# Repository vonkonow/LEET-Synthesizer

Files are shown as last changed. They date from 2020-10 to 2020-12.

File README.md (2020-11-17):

# LEET-Synthesizer
This is the GitHub repository containing the 3D models and source code for the LEET Synthesizer devices: https://vonkonow.com/wordpress/leet-synthesizer/

Description: LEET is a modular & affordable ($6) MIDI synth for your favorite DAW.

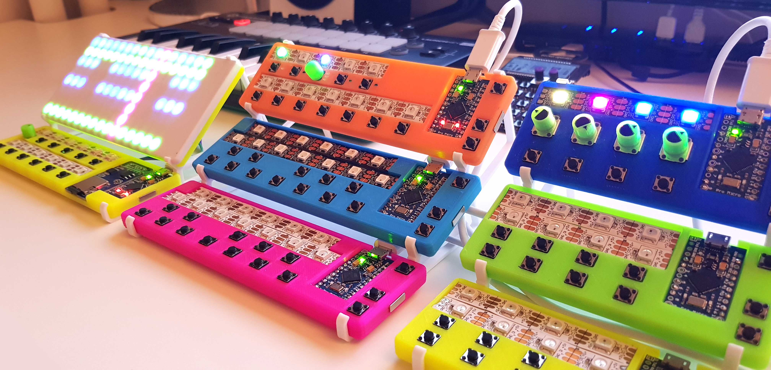
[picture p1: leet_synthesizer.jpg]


I have designed a keyboard, drum pad, chord keyboard, arpeggiator and a step sequencer all with RGB LEDs for playback visualization.
They are easy to build and anyone with a 3D printer and basic soldering skills should be able to replicate them. Everything is open source and hacking is encouraged!

Check out the forum where you can get support and subscribe to get noticed when new devices are released: https://vonkonow.com/wordpress/forums/topic/project-updates/

For detailed building instructions visit: https://vonkonow.com/wordpress/leet-synthesizer/

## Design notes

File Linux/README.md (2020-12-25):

This is the GitHub repository containing the 3D models and files for the LEET Linux device: https://vonkonow.com/wordpress/leet-linux/
Description:
Linux based sound synthesis for LEET modules (or any other MIDI keyboard). Different sound engines can be loaded for high quality sound instruments.

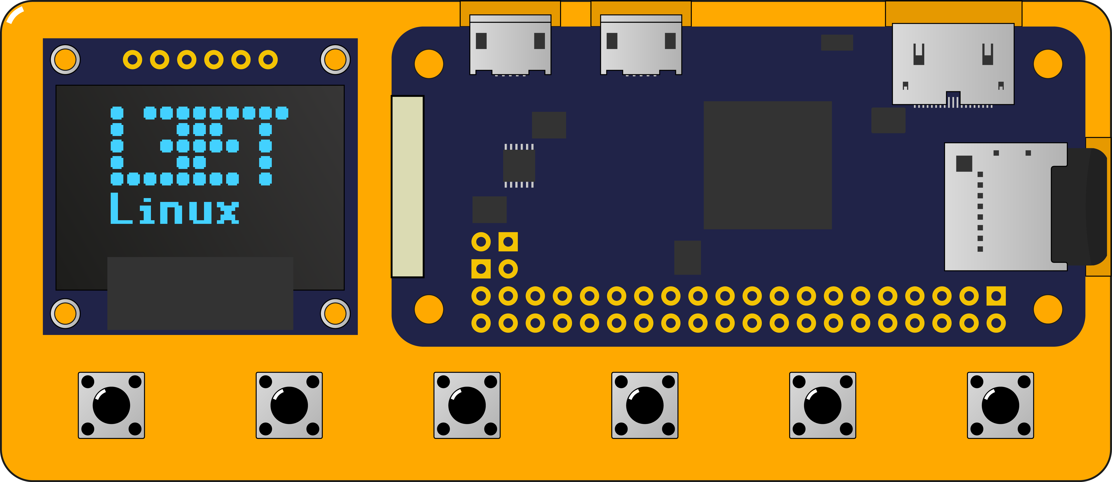
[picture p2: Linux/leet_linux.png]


The parent project (LEET Synthesizer) also contains; a keyboard, drum pad, chord keyboard, control, arpeggiator and a step sequencer, all with RGB LEDs for playback visualization. They are easy to build and anyone with a 3D printer and basic soldering skills should be able to replicate them. Everything is open source and hacking is encouraged!
For detailed building instructions visit: https://vonkonow.com/wordpress/leet-linux/

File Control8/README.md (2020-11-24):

This is the GitHub repository containing the 3D models and source code for the LEET Control8: https://vonkonow.com/wordpress/leet-control8/

Description:

The LEET Control8 is a miniature MIDI accessory suitable for controlling up to eight analog settings in your DAW, like; volume, oscillators, envelope or filters. It is low cost, easy to build and compact in size. 

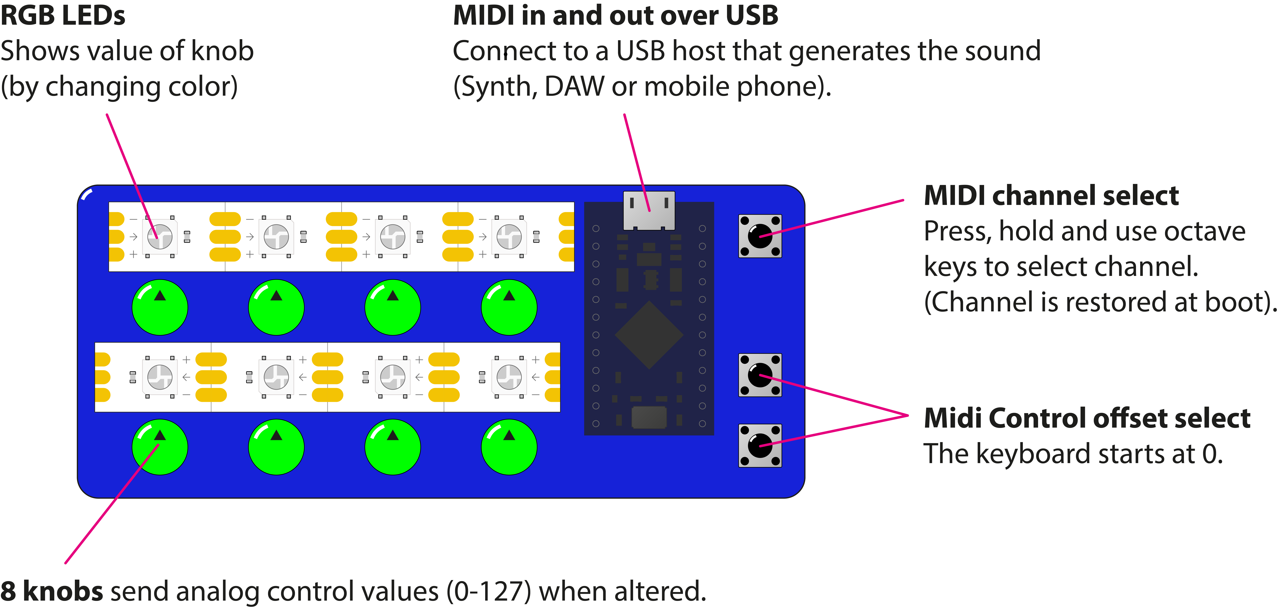
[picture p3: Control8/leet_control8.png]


The parent project (LEET Synthesizer) also contains; a keyboard, drum pad, chord keyboard, arpeggiator and a step sequencer, all with RGB LEDs for playback visualization. They are easy to build and anyone with a 3D printer and basic soldering skills should be able to replicate them. Everything is open source and hacking is encouraged!

For detailed building instructions visit: https://vonkonow.com/wordpress/leet-control8/

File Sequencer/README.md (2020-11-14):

This is the GitHub repository containing the 3D models and source code for the LEET sequencer: https://vonkonow.com/wordpress/leet-sequencer/

## Description:
The LEET Sequencer is a miniature 16-step MIDI sequencer with 8 channels. It is low cost, easy to build and compact in size. It has full color LED blinkenlights for playback and record visualization.

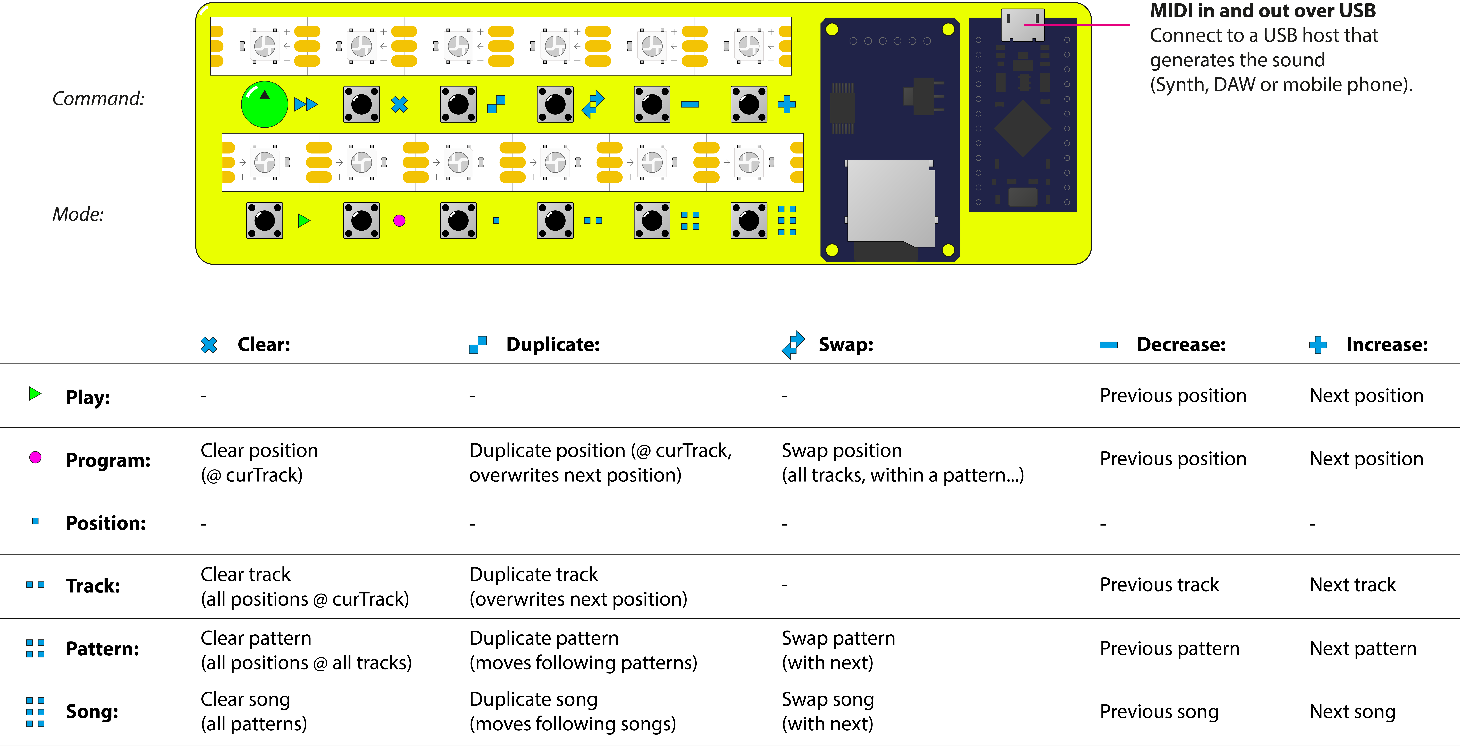
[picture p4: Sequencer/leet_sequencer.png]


The parent project (LEET Synthesizer) also contains; a keyboard, drum pad, chord keyboard, control unit and arpeggiator, all with RGB LEDs for playback visualization. They are easy to build and anyone with a 3D printer and basic soldering skills should be able to replicate them. Everything is open source and hacking is encouraged!

For building instructions visit: https://vonkonow.com/wordpress/leet-sequencer/

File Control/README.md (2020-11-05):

This is the GitHub repository containing the 3D models and source code for the LEET Control: https://vonkonow.com/wordpress/leet-control/

Description: 

The LEET Control is a miniature MIDI accessory suitable for controlling settings in your DAW, like volume, decay or filters. 
It is low cost, easy to build and compact in size. With a different firmware it can also work as an arpeggiator.

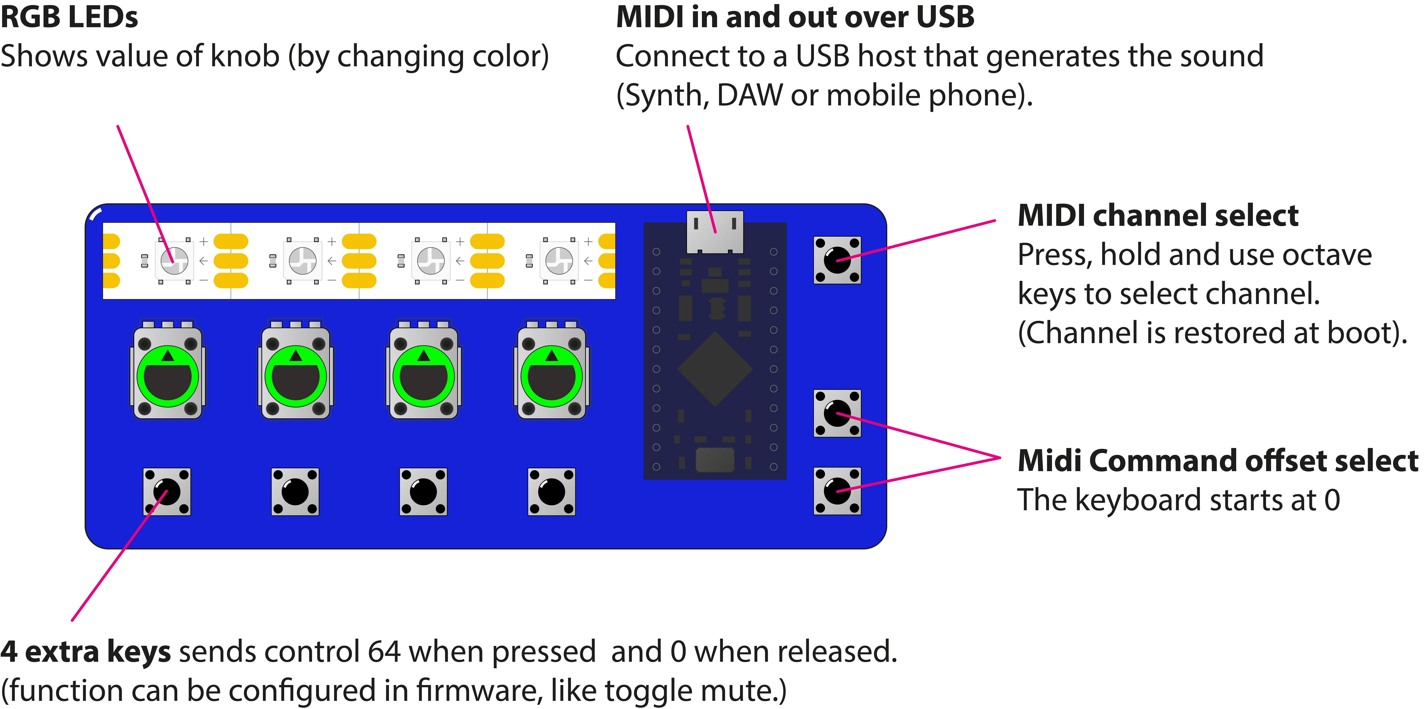
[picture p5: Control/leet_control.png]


The [parent project (LEET Synthesizer)](https://vonkonow.com/wordpress/leet-synthesizer/) also contains; a drum pad, chord keyboard, arpeggiator and a step sequencer, all with RGB LEDs for playback visualization.
They are easy to build and anyone with a 3D printer and basic soldering skills should be able to replicate them. Everything is open source and hacking is encouraged!

For detailed building instructions visit: https://vonkonow.com/wordpress/leet-control/

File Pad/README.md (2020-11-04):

This is the GitHub repository containing the 3D models and source code for the LEET pad: https://vonkonow.com/wordpress/leet-pad/

Description: 

The LEET Pad is a miniature MIDI keyboard suitable for drums and effects. 
It is low cost, easy to build and compact in size. It has full color LED blinkenlights for playback visualization.

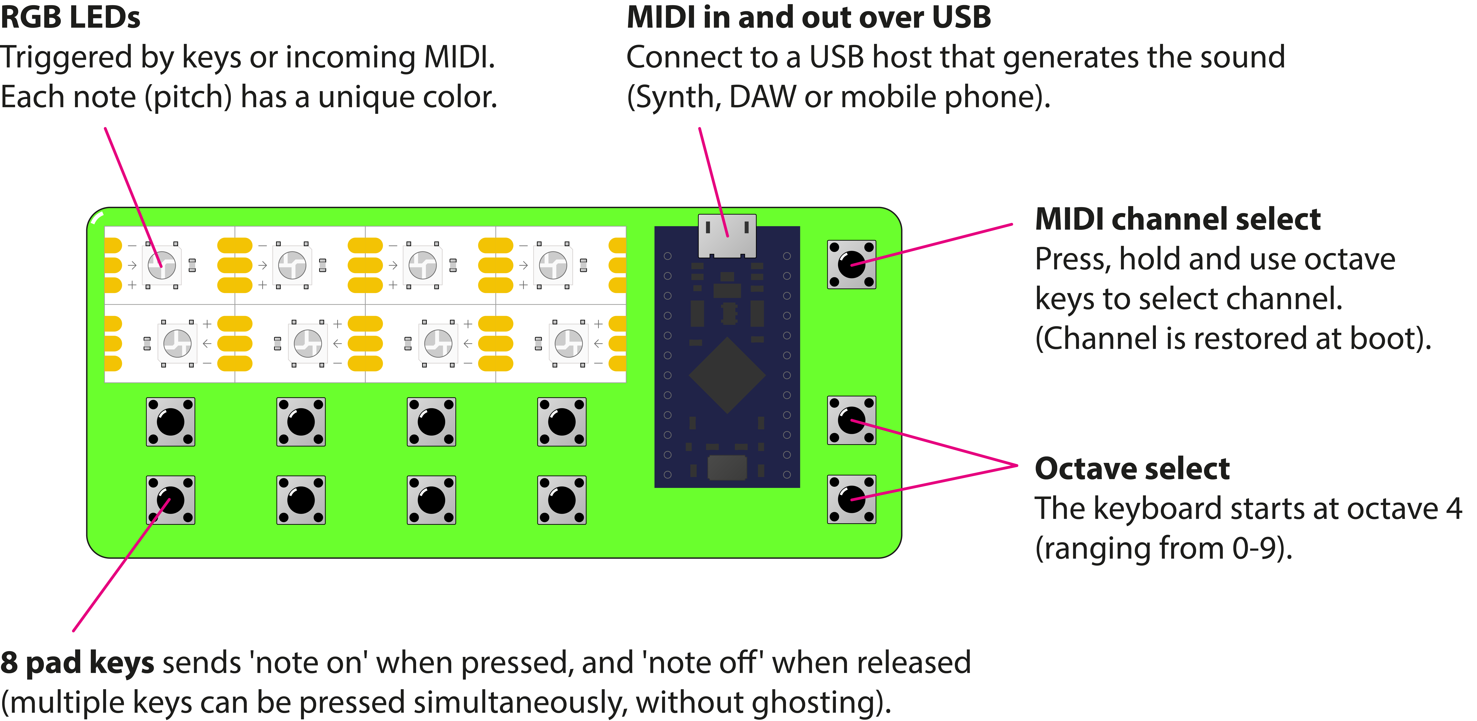
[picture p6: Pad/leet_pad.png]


The [parent project (LEET Synthesizer)](https://vonkonow.com/wordpress/leet-synthesizer/) also contains; a drum pad, chord keyboard, arpeggiator and a step sequencer, all with RGB LEDs for playback visualization.
They are easy to build and anyone with a 3D printer and basic soldering skills should be able to replicate them. Everything is open source and hacking is encouraged!

For detailed building instructions visit: https://vonkonow.com/wordpress/leet-pad/

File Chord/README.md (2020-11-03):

This is the GitHub repository containing the 3D models and source code for the LEET Chord keyboard: https://vonkonow.com/wordpress/leet-chord/

Description: 

The LEET Chord keyboard is a MIDI keyboard that plays chords of your choice. It is easy to build, affordable and has beautiful RGB LED blinkenlights. Adjust number of notes, scale, tonic and root. It is perfect for chord progressions (I – V – vi – IV ;)

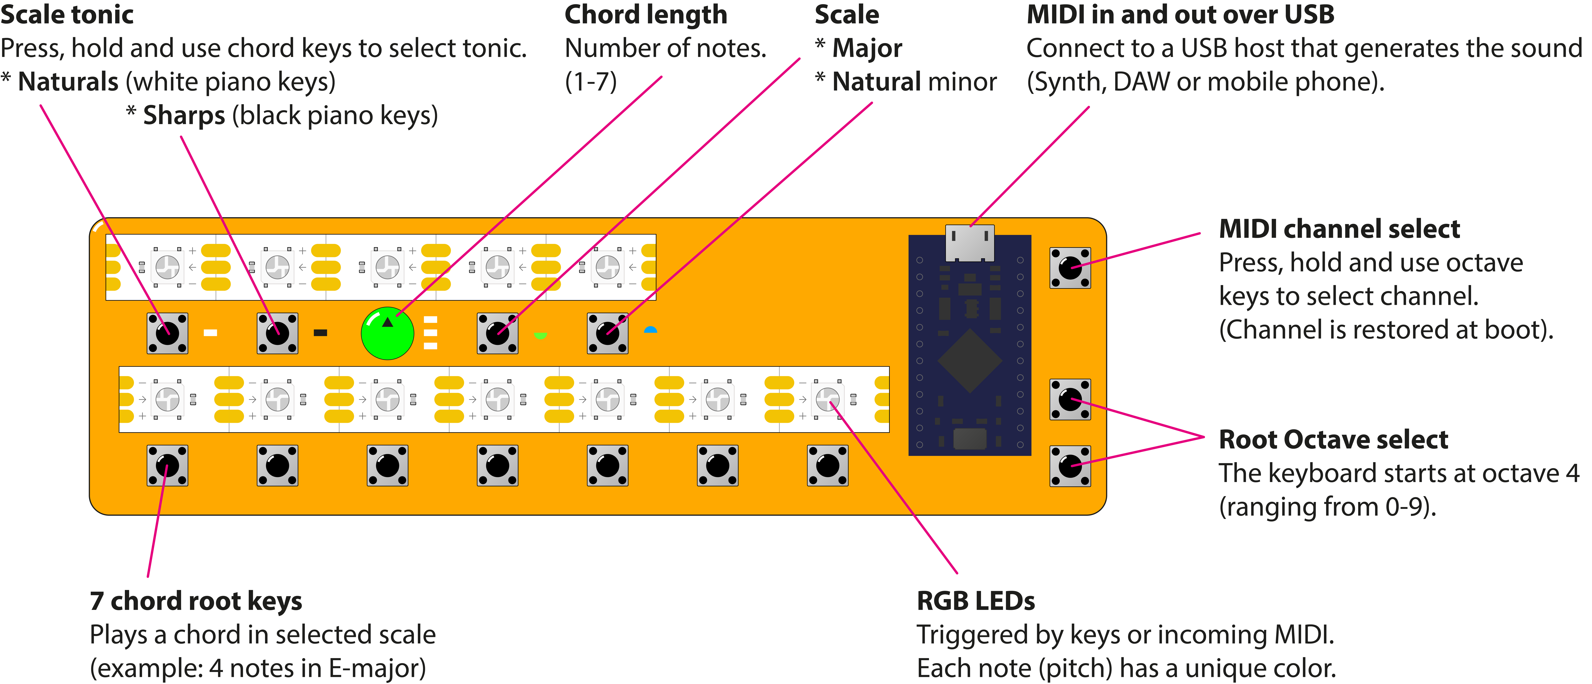
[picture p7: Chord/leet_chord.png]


The [parent project (LEET Synthesizer)](https://vonkonow.com/wordpress/leet-synthesizer/) also contains; a drum pad, chord keyboard, arpeggiator and a step sequencer, all with RGB LEDs for playback visualization.
They are easy to build and anyone with a 3D printer and basic soldering skills should be able to replicate them. Everything is open source and hacking is encouraged!

For detailed building instructions visit: https://vonkonow.com/wordpress/leet-chord/

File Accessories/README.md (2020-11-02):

# This folder contains the 3D models for LEET accessories, like stands, knobs, nametag and clip. 
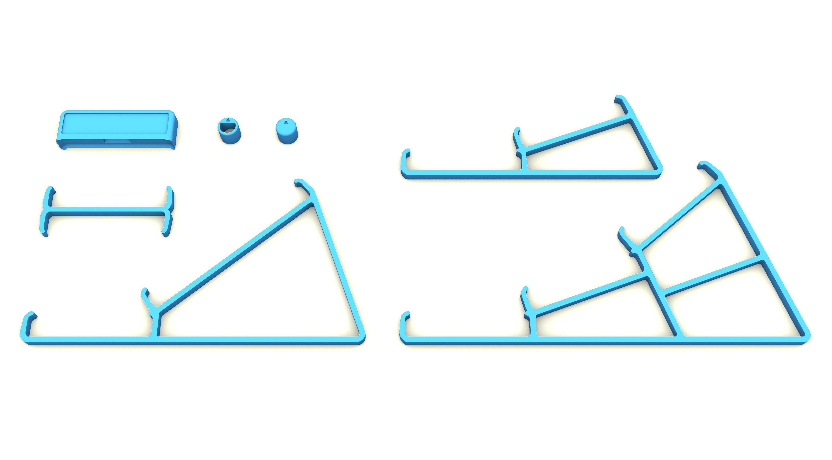
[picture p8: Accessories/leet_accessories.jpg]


## Stands and clip:
The stands and clip are used to group LEET devices in 3D. They are 0.2mm smaller than the units in order to tightly secure them. It is rather important that your 3D printer has a correct flow (too much and the fit will be too tight, too low and the fit will be too loose).
The clip_dual is used to hold two units in place for transportation (positioned back to back if they have a protruding knob).
It is preferred to print the stands and clip in PET as it has good impact resistance (but PLA will also work). Always print two of each.

## Knobs:
I have used two different potentiometers in the LEET project (hence the two different knobs). 
*	High-end potentiometer with short shaft (called RK09K, RK09D, RV09 or PTV09A etc.)
*	Compact and low cost trimpot.

If you have any preference – let me know in the forum.

## Nametag:
The nametag is a snap on accessory that just contains a sticker in order to identify the units. For example “Lead, ch2” or “Drums, ch7”. Please note that the nametag is held in place with neodymium magnets (10x3x2mm), these are otherwise optional.

## LEET Synthesizer:
The parent project contains; a keyboard, drum pad, chord keyboard, arpeggiator and a step sequencer, all with RGB LEDs for playback visualization.
They are easy to build and anyone with a 3D printer and basic soldering skills should be able to replicate them. Everything is open source and hacking is encouraged!
For more information about the LEET Synthesizer visit: https://vonkonow.com/wordpress/leet-synthesizer/

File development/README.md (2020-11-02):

This folder is for content under development.
The files here are not tested and should be seen as work in progress. 

Print and use at own risk ;)

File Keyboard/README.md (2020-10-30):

This is the GitHub repository containing the 3D models and source code for the single octave LEET keyboard: https://vonkonow.com/wordpress/leet-keyboard/

Description: 

The LEET keyboard is a modular & affordable ($6) MIDI keyboard for your favorite DAW.

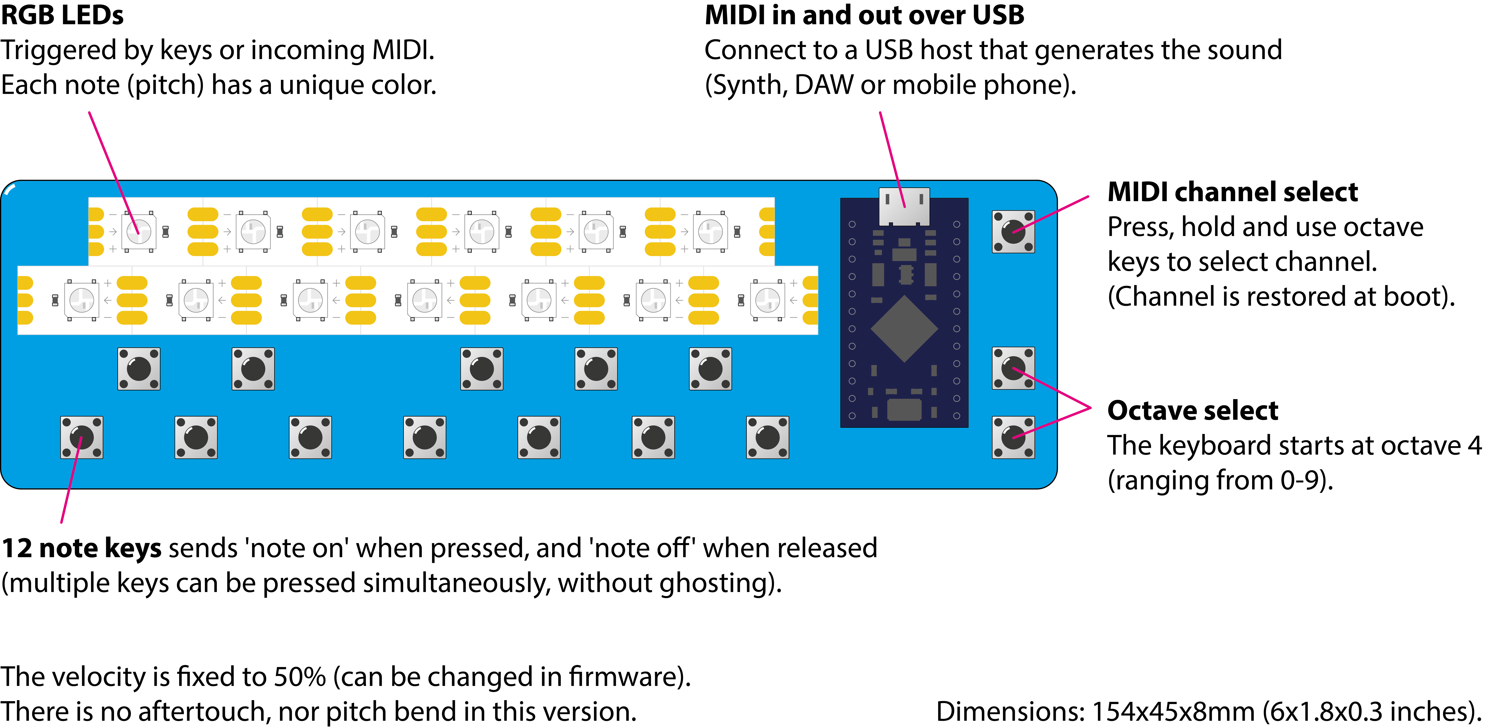
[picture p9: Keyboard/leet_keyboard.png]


The [parent project (LEET Synthesizer)](https://vonkonow.com/wordpress/leet-synthesizer/) also contains; a drum pad, chord keyboard, arpeggiator and a step sequencer, all with RGB LEDs for playback visualization.
They are easy to build and anyone with a 3D printer and basic soldering skills should be able to replicate them. Everything is open source and hacking is encouraged!

For detailed building instructions visit: https://vonkonow.com/wordpress/leet-keyboard/

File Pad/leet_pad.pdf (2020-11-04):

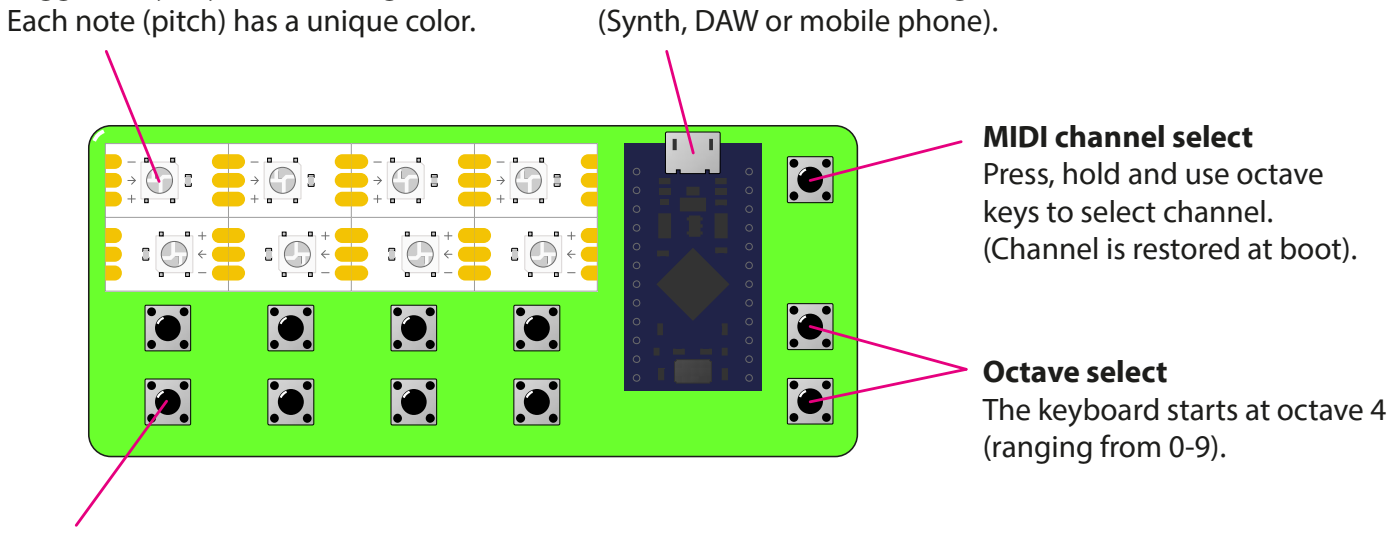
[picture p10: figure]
Octave select The keyboard starts at octave 4 (ranging from 0-9).; MIDI channel select Press, hold and use octave keys to select channel. (Channel is restored at boot).; Each note (pitch) has a unique color.; (Synth, DAW or mobile phone).

### 8 pad keys sends 'note on' when pressed, and 'note off' when released

(multiple keys can be pressed simultaneously, without ghosting).

The velocity is öxed to 50% (can be changed in örmware). There is no aftertouch, nor pitch bend in this version.

RGB LEDs
Triggered by keys or incoming MIDI.

Dimensions: 104x45x8mm (6x1.8x0.3 inches).

MIDI in and out over USB
Connect to a USB host that generates the sound

## LEET pad keyboard

Visit www.vonkonow.com for details, öles and build instruction.

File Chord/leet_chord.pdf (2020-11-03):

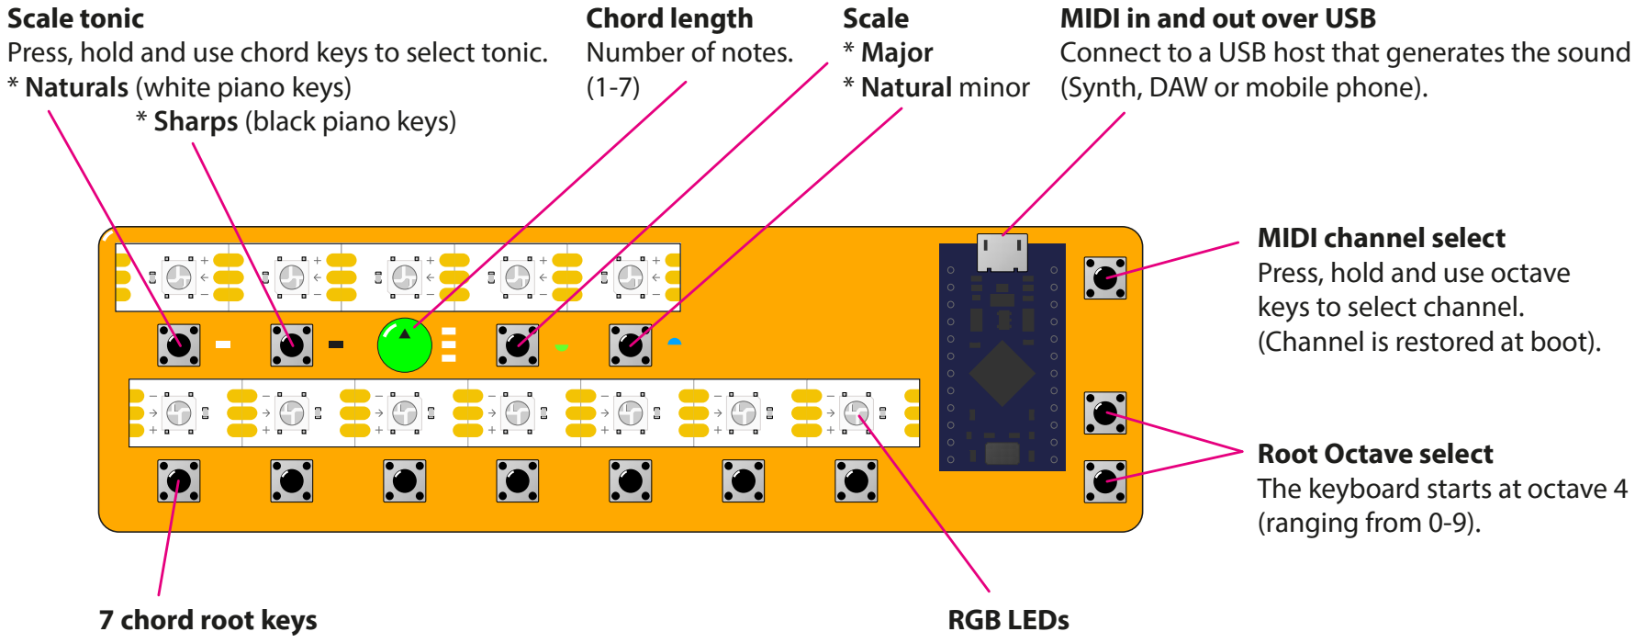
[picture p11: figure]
7 chord root keys; Root Octave select The keyboard starts at octave 4 (ranging from 0-9).; MIDI channel select Press, hold and use octave keys to select channel. (Channel is restored at boot).; RGB LEDs; MIDI in and out over USB; (Synth, DAW or mobile phone).; Scale tonic; * Naturals (white piano keys) * Sharps (black piano keys); Scale * Major * Natural minor; Chord length Number of notes. (1-7)

Plays a chord in selected scale (example: 4 notes in E-major)

The velocity is öxed to 50% (can be changed in örmware). There is no aftertouch, nor pitch bend in this version.

Triggered by keys or incoming MIDI. Each note (pitch) has a unique color.

Dimensions: 154x45x8mm (6x1.8x0.3 inches).

Connect to a USB host that generates the sound

## LEET chord keyboard

Visit www.vonkonow.com for details, öles and build instruction.

Press, hold and use chord keys to select tonic.

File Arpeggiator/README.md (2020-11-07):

This is the GitHub repository containing the 3D models and source code for the LEET Arpeggiator: https://vonkonow.com/wordpress/leet-arpeggiator/

Description: 

The LEET Arpeggiator is a proof of concept of a miniature MIDI arpeggiator using the same hardware as LEET Control. It is low cost, easy to build and compact in size. 

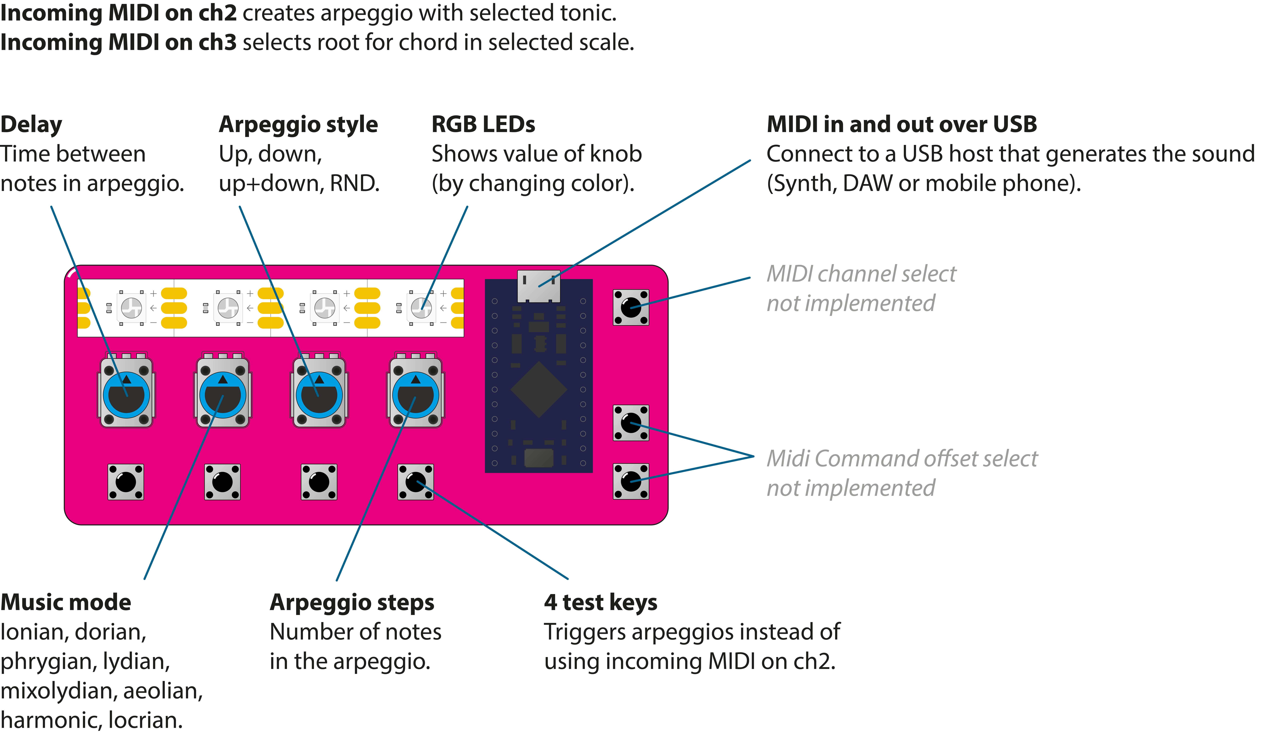
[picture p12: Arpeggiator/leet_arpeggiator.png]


This project is an experiment to see how an arpeggiator could be implemented using the control hardware. 
It is a proof of concept where I have merged [Dmirys arpeggiator1 project](https://github.com/raszhivin/arpeggiator) with the [control surface library](https://github.com/tttapa/Control-Surface) and adjusted it to the control hardware. 
There is no selection of octaves or midi channel and the four note keys are not in order… 

The [parent project (LEET Synthesizer)](https://vonkonow.com/wordpress/leet-synthesizer/) also contains; a drum pad, chord keyboard, arpeggiator and a step sequencer, all with RGB LEDs for playback visualization.
They are easy to build and anyone with a 3D printer and basic soldering skills should be able to replicate them. Everything is open source and hacking is encouraged!

For detailed building instructions visit: https://vonkonow.com/wordpress/leet-arpeggiator/

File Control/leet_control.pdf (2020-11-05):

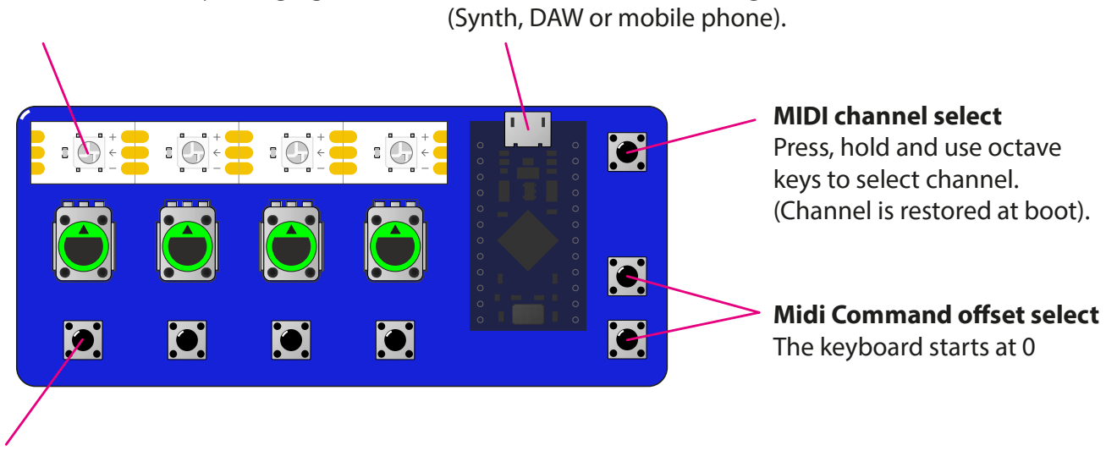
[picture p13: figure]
Midi Command offset select The keyboard starts at 0; MIDI channel select Press, hold and use octave keys to select channel. (Channel is restored at boot).; (Synth, DAW or mobile phone).

4 extra keys sends control 64 when pressed and 0 when released. (function can be conögured in örmware, like toggle mute.)

The same hardware can be used as arpeggiator by downloading a different örmware.

RGB LEDs
Shows value of knob (by changing color)

Dimensions: 104x45x8mm (6x1.8x0.3 inches).

MIDI in and out over USB
Connect to a USB host that generates the sound

## LEET Control

Visit www.vonkonow.com for details, öles and build instruction.

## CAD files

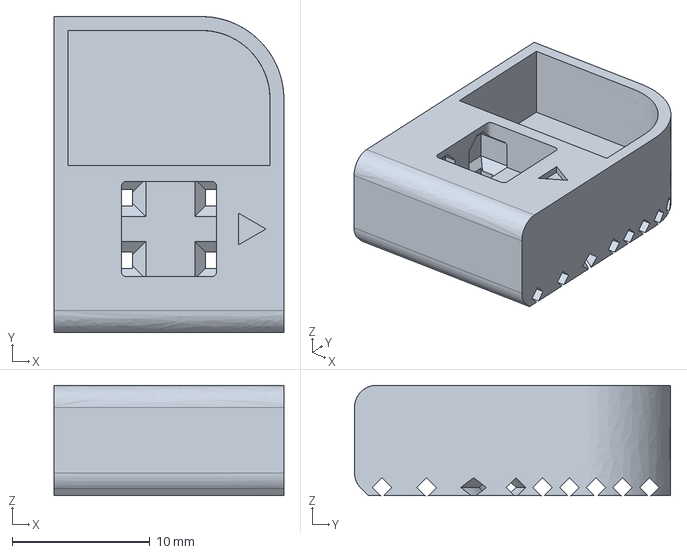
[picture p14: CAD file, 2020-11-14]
Accessories/3DPrinter_test/leet_test.stp
16.7 x 22.9 x 8.00 mm

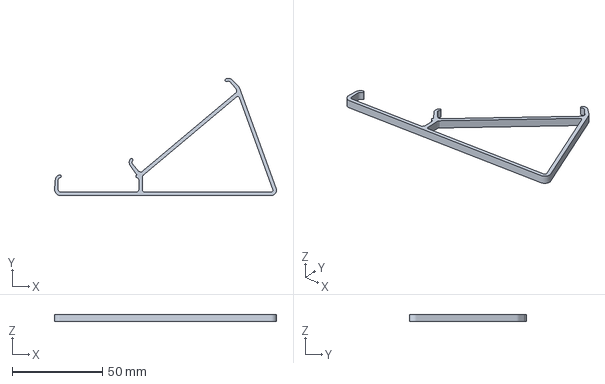
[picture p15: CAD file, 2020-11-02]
Accessories/leet_clip_stand_seq.stp
122.9 x 64.9 x 4.00 mm

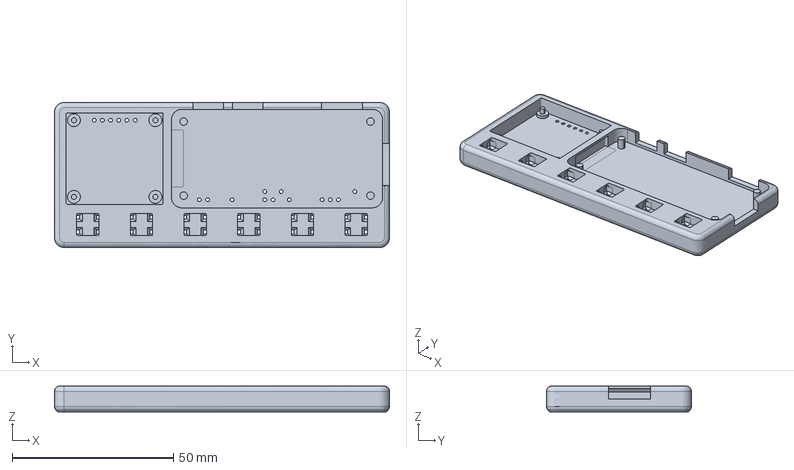
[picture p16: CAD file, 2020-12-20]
Linux/leet_linux.stp
104.0 x 45.0 x 8.00 mm

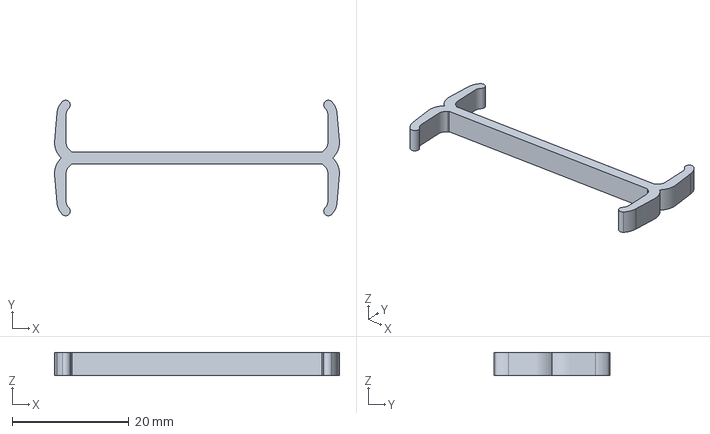
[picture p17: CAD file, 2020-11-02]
Accessories/leet_clip_dual.stp
48.8 x 19.8 x 4.00 mm

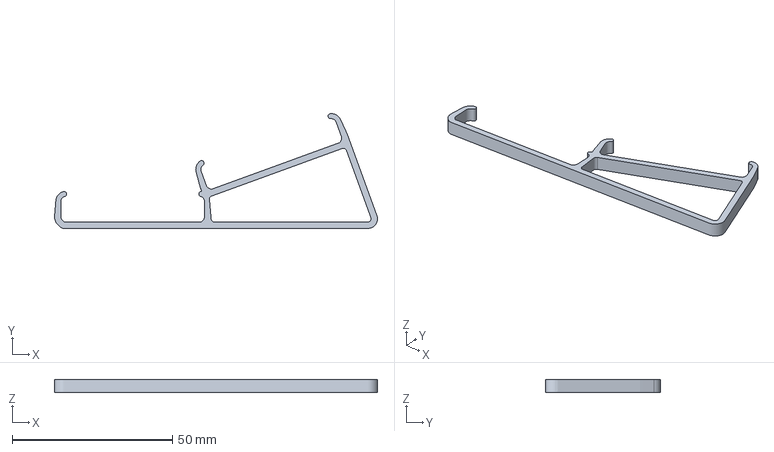
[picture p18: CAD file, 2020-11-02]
Accessories/leet_clip_stand2.stp
100.8 x 35.8 x 4.00 mm

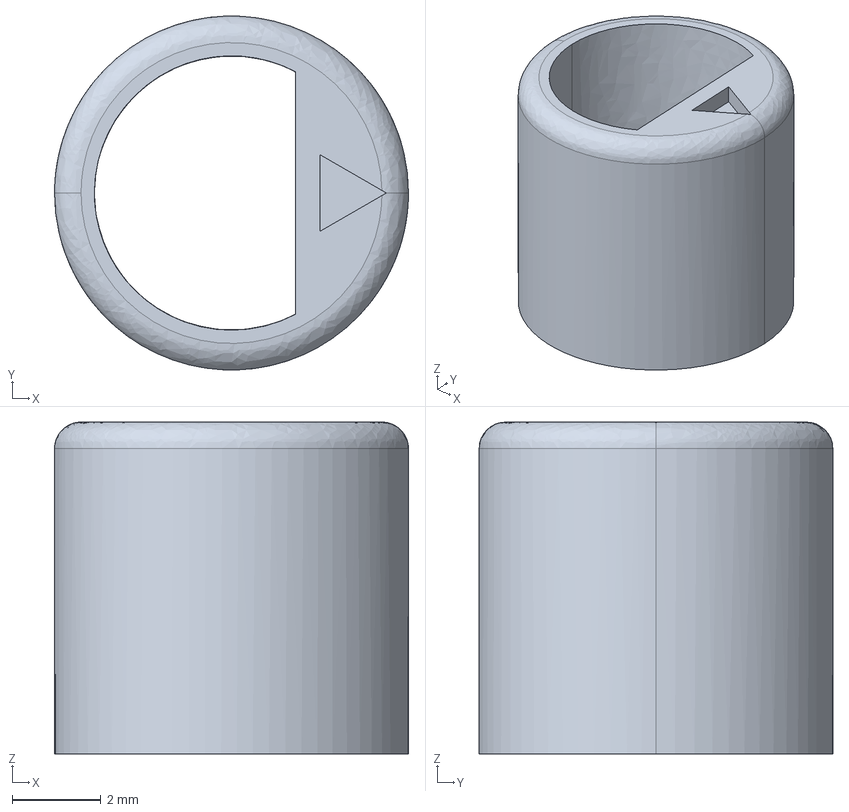
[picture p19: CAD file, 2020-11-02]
Accessories/knob_pot.stp
8.00 x 8.00 x 7.50 mm

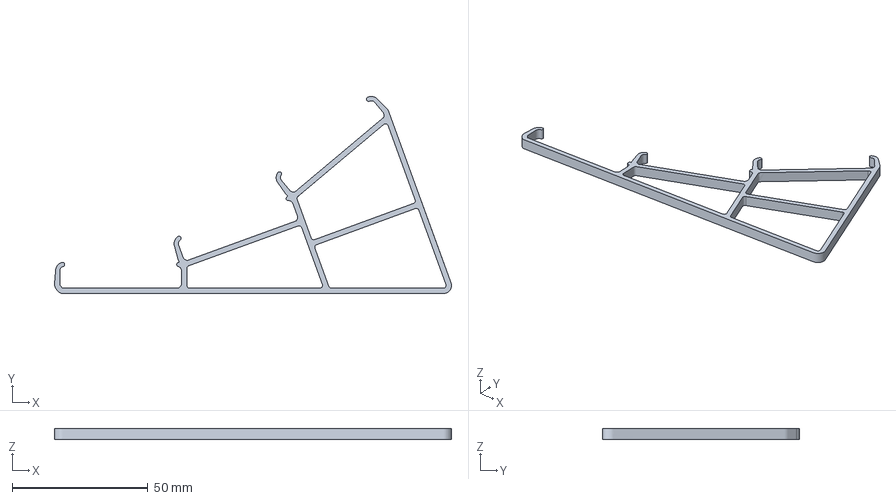
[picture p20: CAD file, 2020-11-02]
Accessories/leet_clip_stand3.stp
146.3 x 72.6 x 4.00 mm

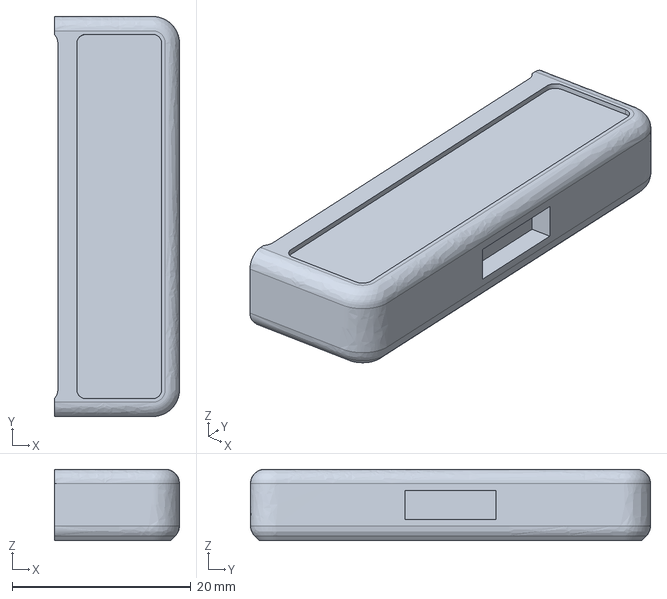
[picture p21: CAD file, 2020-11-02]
Accessories/leet_label.stp
14.0 x 44.8 x 8.00 mm

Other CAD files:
Accessories/knob_trim.stp
Accessories/3DPrinter_test/leet_test.stl
Accessories/knob_pot.stl
Accessories/knob_trim.stl
Accessories/leet_clip_dual.stl
Accessories/leet_clip_stand2.stl
Accessories/leet_clip_stand3.stl
Accessories/leet_clip_stand_seq.stl
Accessories/leet_label.stl

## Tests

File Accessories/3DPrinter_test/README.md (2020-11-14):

# This folder contains a 3D model suitable for calibrating your fff/fdm 3DPrinter without having to spend time and filament on a bigger leet model. 
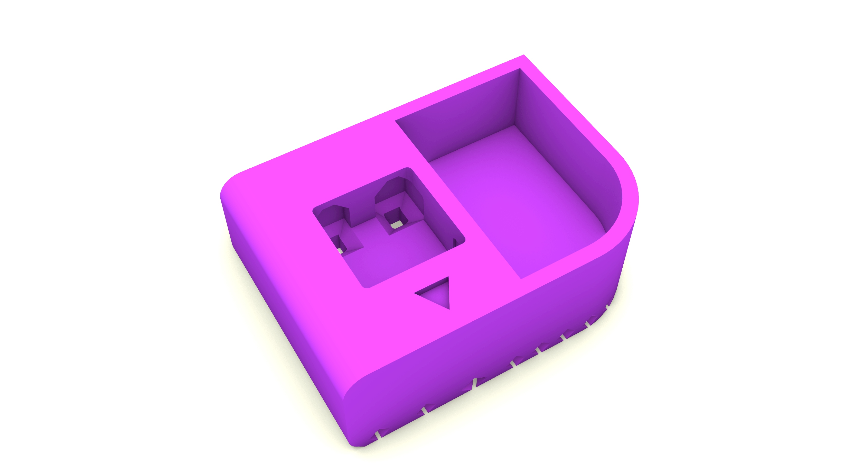
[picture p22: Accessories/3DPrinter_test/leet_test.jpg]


Print the stl file with standard settings:
*	Material: PLA
*	Nozzle temperature: 210deg C
*	Nozzle opening diameter: 0.4mm
*	Layer height: 0.2mm
*	Infill: 20%
*	Support: None

The backside should be smooth with openings for the wire paths:
1.	Measure the thickness of the upper wall with a caliper. Adjust flow and reprint until the wall thickness is 1mm. 
2.	If wire paths are closed on the bottom increase first layer height (z nozzle distance). 
3.	Once the wire channels looks ok, test inserting a 6x6mm tact switch to see how it fits.

Good luck!

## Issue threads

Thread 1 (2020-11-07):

LEET Control Small Mistake in the Model

shortlurker, 2020-11-07:
One of the wire routing channels for the pot closest to the Arduino has a small mistake that will have 3D printer print in the air printed as is.
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

vonkonow, 2020-11-07:
Thank you for the feedback.
There are lots of similar things in the models that probably should be corrected, but this one is one of the stranger ;) Each model has over 1000 surfaces and I have printed all devices with acceptable result, so unless they create major errors, I will focus on releasing the remaining devices first.  Check out this post regarding 3D-printing issues:
https://vonkonow.com/wordpress/forums/topic/printing-the-3dpcb/

The control device is a test I did to try three things at once:
Potentiometer control, arpeggiator base and high quality potentiometers. I will probably evolve this into one dedicated control (with more knobs: https://vonkonow.com/wordpress/forums/topic/more-knobs/ ) and one dedicated arpeggiator (rendering this version obsolete).
I’m also leaning against using the smaller and cheaper trimpot potentiometers since they are more compact, easier to route and integrates better.

shortlurker, 2020-11-07:
You're welcome. I really like that you've designed the models to be printed without supports. And I'm fairly sure if I printed this model even with that minor error it would sort itself out after a few layers later.

This model fits exactly what I want while I've been working on a physical controller for Voicemeeter Banana as I have time. I do want to modify it to fit a rotary encoder some time.

Thank you for creating and sharing this!

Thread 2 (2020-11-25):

What kind of wire?

ARKopp, 2020-11-25:
hallo can put a link for this specific small wire up. I do not undestand what I need to get.

vonkonow, 2020-11-26:
Hi
Most wires will work, People have done it with the thicker Ethernet cable.
Personally, I like 0.3mm - Check out this post: https://vonkonow.com/wordpress/forums/topic/what-is-rk-wire/

Closed 2020-11-26.

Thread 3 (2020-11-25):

Holes missing

ARKopp, 2020-11-25:
Can you put all the holes for the arduino in.

Now you have to clip of some legs

vonkonow, 2020-11-26:
Hi
The idea is to use a pro micro _without_ pin header. I have deliberately not added holes to make it easier to see if any wires are missing. Please also note that there are wires routed under some of the pins, so there is a risk of short circuit if pins are kept…
I recommend to de-solder the pin header, but you can try to drill holes if needed (a tip: make a small dimple with the soldering iron first).

Closed 2021-01-09.

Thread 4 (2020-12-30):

LEET-Linux: Issue loading sample files.

rynfox13, 2020-12-30:
I found an issue in [Linux/SamplerBoxFiles.zip:samplerbox.py](https://github.com/vonkonow/LEET-Synthesizer/blob/main/Linux/SamplerBoxFiles.zip) where the sample files (downloaded from [SamplerBox](https://www.samplerbox.org/instruments)) were not loading.

Here's my fix:

```diff
pi@leet-linux:~/SamplerBox $ diff samplerbox.py samplerbox.py.orig
298,299c298,299
<                     pattern = pattern.replace(r"%midinote", r"(?P<midinote>\d+)").replace(r"%velocity", r"(?P<velocity>\d+)")\
<                                      .replace(r"%notename", r"(?P<notename>[A-Ga-g]#?[0-9])").replace(r"\*", r".*?").strip()    # .*? => non greedy
---
>                     pattern = pattern.replace(r"\%midinote", r"(?P<midinote>\d+)").replace(r"\%velocity", r"(?P<velocity>\d+)")\
>                                      .replace(r"\%notename", r"(?P<notename>[A-Ga-g]#?[0-9])").replace(r"\*", r".*?").strip()    # .*? => non greedy
```

I hope this helps.

vonkonow, 2021-01-11:
Thank you for finding this error. It solved the problem with the sample sets!
I have fixed and uploaded the file.

Closed 2021-01-11.

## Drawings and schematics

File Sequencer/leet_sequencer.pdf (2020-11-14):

# LEET Sequencer

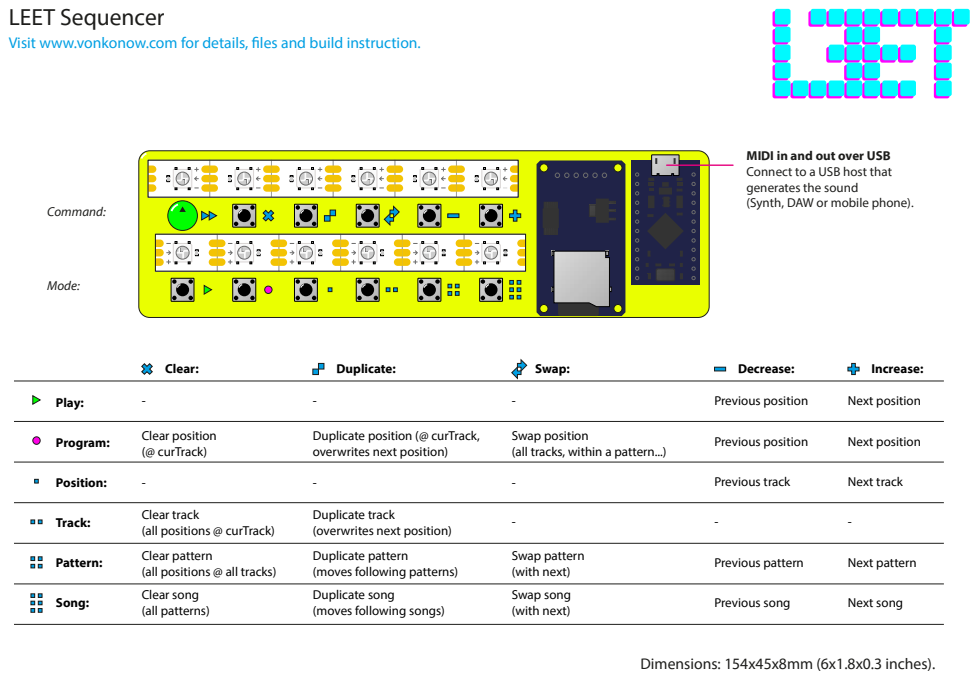
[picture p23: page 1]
Clear:; Command:; Mode:; Previous song; Next song Swap song; (with next); Previous track; Next track; Previous position; Next position; Song:; Pattern:; Track:; Position:; Previous pattern; Next pattern Swap pattern; Next position Swap position; Clear position (@ curTrack); Program:; Play:; Swap:; Decrease:; Increase:; Dimensions: 154x45x8mm (6x1.8x0.3 inches).; Duplicate:

Visit www.vonkonow.com for details, öles and build instruction.

MIDI in and out over USB
Connect to a USB host that
generates the sound
(Synth, DAW or mobile phone).

Duplicate position (@ curTrack,
overwrites next position)

(all tracks, within a pattern...)

Clear track
(all positions @ curTrack)
Clear pattern
(all positions @ all tracks)
Clear song
(all patterns)

Duplicate track
(overwrites next position)
Duplicate pattern
(moves following patterns)
Duplicate song
(moves following songs)

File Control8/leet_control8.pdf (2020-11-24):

## LEET Control8

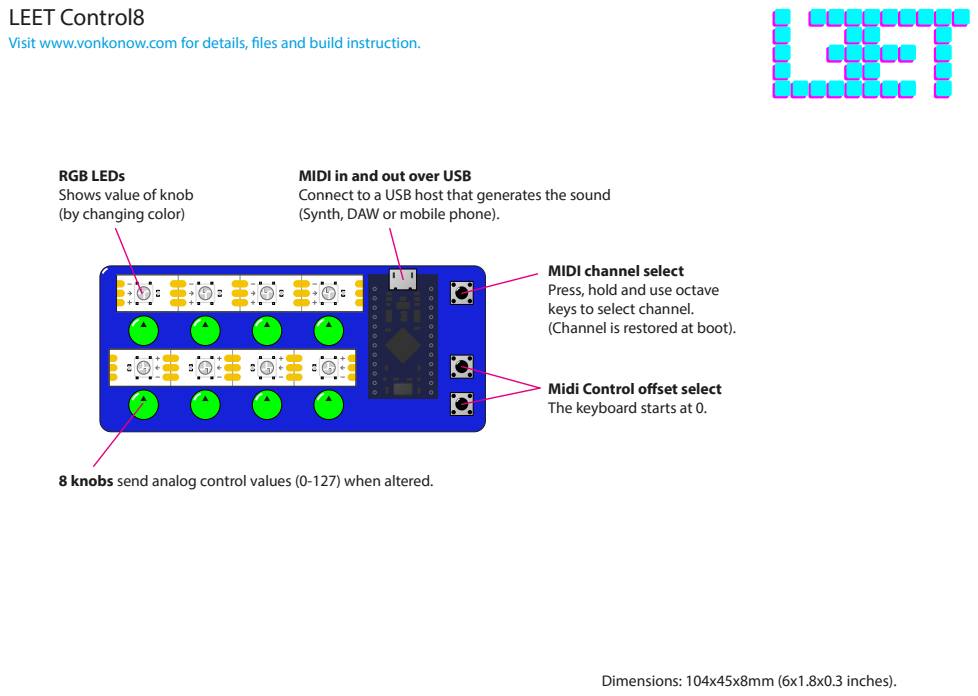
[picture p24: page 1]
Dimensions: 104x45x8mm (6x1.8x0.3 inches).

Visit www.vonkonow.com for details, öles and build instruction.

RGB LEDs
Shows value of knob
(by changing color)

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

Midi Control offset select
The keyboard starts at 0.

8 knobs send analog control values (0-127) when altered.

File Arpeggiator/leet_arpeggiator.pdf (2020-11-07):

## LEET Arpeggiator POC

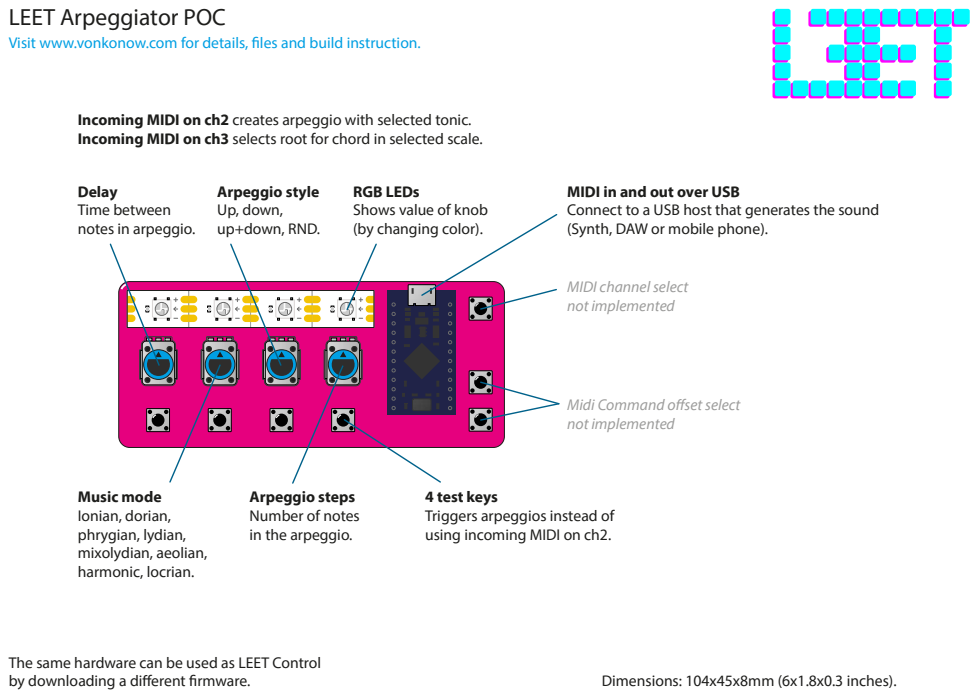
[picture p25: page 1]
Dimensions: 104x45x8mm (6x1.8x0.3 inches).; Music mode Ionian, dorian, phrygian, lydian, mixolydian, aeolian, harmonic, locrian.

Visit www.vonkonow.com for details, öles and build instruction.

Incoming MIDI on ch2 creates arpeggio with selected tonic.
Incoming MIDI on ch3 selects root for chord in selected scale.

Delay
Time between
notes in arpeggio.

Arpeggio style
Up, down,
up+down, RND.

RGB LEDs
Shows value of knob
(by changing color).

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

MIDI channel select
not implemented

Midi Command offset select

Arpeggio steps
Number of notes
in the arpeggio.

4 test keys
Triggers arpeggios instead of
using incoming MIDI on ch2.

The same hardware can be used as LEET Control
by downloading a different örmware.

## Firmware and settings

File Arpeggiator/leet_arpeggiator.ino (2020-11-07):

//-----10|-------20|-------30|-------40|-------50|-------60|-------70|-------80|
//
// -=*** LEET Arpeggiator POC ***=-
//
// The device sends configurable arpeggios as MIDI commands over USB.
// Uses Arduino pro micro (atMega32U4), WS2812 led strips & 7 keys
// connected between microcontroller and GND (using weak pull-ups).
// Latest version, details and build instructions is found on www.vonkonow.com
//
// This project is an experiment to see how an arpeggiator could be
// implemented using the control hardware. It is a proof of concept where I
// have merged Dmirys arpeggiator1 project with the control surface library
// and adjusted it to the control hardware. There is no selection of octaves
// or midi channel and the four note keys are not in order… 
// The implementation is using incoming MIDI signals to select chord note
// (ch3) and arpeggio note (ch2). By using two LEET keyboards and reroute the
// MIDI signals thru the DAW to the arpeggiator they can be used for chord and
// arpeggiator control.
// The potentiometers are used to adjust:
// •    Delay between notes (AN9 0-500ms)
// •    Music Mode (AN8 Ionian, dorian, phrygian, lydian, mixolydian, aeolian,
//      harmonic, locrian)
// •    Arpeggio style (AN7 up, down, up+down, rnd)
// •    Arpeggio Steps (AN6 1-6)
// 
// Future development:
// I plan to focus my attention on rebuilding it from scratch rather than
// improving the current state:
// It will likely be based on the chord unit, allowing it to be played without
// incoming midi channels and it will probably be using permissive open source
// instead of the copy left GPL3.0 license used due to the current code base.
// 

#include <TimerOne.h>
#include <FastLED.h>          // Must be before Control Surface to enable FastLED features of Control Surface
#include <Control_Surface.h>  // Include the Control Surface library

Array<CRGB, 4> leds = {};     // Define the array of leds.
constexpr uint8_t ledpin = 2; // The data pin with the strip connected.
const uint8_t ledId[4] = {3, 2, 1, 0};

typedef enum {C, CD, D, DD, E, F, FD, G, GD, A, AD, B} notes;
typedef enum {maj, minor, dim, aug} chord_types;

typedef struct {
  short Shift;
  chord_types chord_type;
} chord;

class arp {
  private:
    notes baseNote;
    short baseOctave;
    short octaveShift;
    short steps;
    //unsigned int mode[6];
    short indelay;
    int progression;
    chord *mode;
    int order;
  public:
    arp();
    arp(notes bn, short bo, short os, unsigned short st, unsigned int d, unsigned m, unsigned int p);
    void setupArp(short bn, short bo, short os, unsigned short st, unsigned int d, int m, unsigned imode);
    int setProgression(unsigned int p);
    void play();
    void midibegin();
};

int* createChord(notes root, chord_types i, int *notes_array, unsigned short *sh1, unsigned short *sh2);
short midiByNote (notes note, short octave);

#define c_ionian      0
#define c_dorian      1
#define c_phrygian    2
#define c_lydian      3
#define c_mixolydian  4
#define c_aeolian     5
#define c_harmonic    6
#define c_locrian     7
// C Ionian     { C maj;  D min;  E min;  F maj;  G maj;  A min;  B dim  }
const chord ionian[7]     = {{0, maj},    {2, minor}, {4, minor}, {5, maj},   {7, maj},   {9, minor}, {11, dim}};
// C Dorian     { C min;  D min;  D♯ maj; F maj;  G min;  A dim;  A♯ maj  }
const chord dorian[7]     = {{0, minor},  {2, minor}, {3, maj},   {5, maj},   {7, minor}, {9, dim},   {10, maj}};
//C Phrygian    { C min;  C♯ maj; D♯ maj; F min;  G dim;  G♯ maj; A♯ min  }
const chord phrygian[7]   = {{0, minor},  {1, maj},   {3, maj},   {5, minor}, {7, dim},   {8, maj},   {10, minor}};
//C Lydian      { C maj;  D maj;  E min;  F♯ dim; G maj;  A min;  B min   }
const chord lydian[7]     = {{0, maj},    {2, maj},   {4, minor}, {6, dim},   {7, maj},   {9, minor}, {11, minor}};
//C Mixolydian  { C maj;  D min;  E dim;  F maj;  G min;  A min;  A♯ maj  }
const chord mixolydian[7] = {{0, maj},    {2, minor}, {4, dim},   {5, maj},   {7, minor}, {9, minor}, {10, maj}};
//C Aeolian     { C min;  D dim;  D♯ maj; F min;  G min;  G♯ maj; A♯ maj  }
const chord aeolian[7]    = {{0, minor},  {2, dim},   {3, maj},   {5, minor}, {7, minor}, {8, maj},   {10, maj}};
//C harmonic    { C min;  D dim;  D♯ aug; F min;  G maj;  G♯ maj; B dim   }
const chord harmonic[7]   = {{0, minor},  {2, dim},   {3, aug},   {5, minor}, {7, maj},   {8, maj},   {11, dim}};
//C Locrian     { C dim;  C♯ maj; D♯ min; F min;  F♯ maj; G♯ maj; A♯ min  }
const chord locrian[7]    = {{0, dim},    {1, maj},   {3, minor}, {5, minor}, {6, maj},   {8, maj},   {10, minor}};
const chord *all_chords[8] = {ionian, dorian, phrygian, lydian, mixolydian, aeolian, harmonic, locrian};

arp a(C, 5, 2, 6, 200, c_harmonic, 0);
bool button_pressed;
int ButtonVal;

//#define baseNotepin 1
//#define baseOctavepin 5
//#define octaveShiftpin 0
#define indelaypin A9
#define modepin A8
#define orderpin A7
#define stepspin A6
//#define LEDPin 13

// Synchronization: choose one of two possible options:
//#define EXT_SYNC
//#define syncinpin 3
#define INT_SYNC

uint8_t prevstate = 1;
uint8_t midi3note = 0;
uint8_t midi3octave = 4;
uint8_t midi4note = 0;
uint8_t midi4octave = 3;

USBMIDI_Interface midi;     // The MIDI over USB interface to use

// Custom MIDI callback that prints incoming messages.
struct MyMIDI_Callbacks : MIDI_Callbacks {

  // Callback for channel messages (notes, control change, pitch bend, etc.).
  void onChannelMessage(Parsing_MIDI_Interface &midi) override {
    ChannelMessage cm = midi.getChannelMessage();
    // Print the message
    Serial << F("Channel message: ") << hex << cm.header << ' ' << cm.data1
           << ' ' << cm.data2 << dec << F(" on cable ") << cm.CN << endl;
    if (cm.header == (0x90 | 0x03) ) {
      midi4note = cm.data1 % 12;
      midi4octave = cm.data1 / 12;
      button_pressed = true;

      Serial.print("base note:");
      Serial.print(midi4note, HEX);
      Serial.print(" base octave");
      Serial.println(midi4octave, HEX);
    }   
    if (cm.header == (0x90 | 0x02) ) {
      midi3note = cm.data1 % 12;
      midi3octave = cm.data1 / 12;
      button_pressed = true;
      ButtonVal = midi3note;

      Serial.print("arpeggio note:");
      Serial.print(midi3note, HEX);
      Serial.print(" arpeggio octave");
      Serial.println(midi3octave, HEX);
    }
    
  }

  // Callback for system exclusive messages
  void onSysExMessage(Parsing_MIDI_Interface &midi) override {
    SysExMessage se = midi.getSysExMessage();
    // Print the message
    Serial << F("System Exclusive message: ") << hex;
    for (size_t i = 0; i < se.length; ++i)
      Serial << se.data[i] << ' ';
    Serial << dec << F("on cable ") << se.CN << endl;
  }
} callbacks;

void readPots() {
  unsigned i;
  //a.setupArp(analogRead(baseNotepin), analogRead(baseOctavepin), analogRead(octaveShiftpin), analogRead(stepspin), analogRead(indelaypin), analogRead(orderpin), analogRead(modepin));
  a.setupArp(400, 400, 400, analogRead(stepspin), analogRead(indelaypin), analogRead(orderpin), analogRead(modepin));
  for (i = 20; i > 13; i--)     // pin 20,15,14,16 are connected to the four keys at the bottom ***FOR TEST ONLY, NOT IN ORDER***
    if (!(digitalRead(i))) {
      button_pressed = true;
      ButtonVal = 17 - i;
      return;
    }
  midi.update();                  // Continuously handle MIDI input
  FastLED.show();
}

void setup() {
  Serial.begin(115200);
  Serial.print("Serial debug enabled: ");

  FastLED.addLeds<NEOPIXEL, ledpin>(leds.data, leds.length);
  FastLED.setCorrection(TypicalPixelString);
  //Control_Surface.begin();      // Initialize Control Surface
  midi.begin(); // Initialize the MIDI interface
  midi.setCallbacks(callbacks); // Attach the custom callback
  Timer1.initialize(200000);          // initialize timer1, and set a 1/10 second period
  Timer1.attachInterrupt(readPots);   // We will read pots and buttons values within timer interrupt
  // Initialize pins for 2-pins pushbuttons with pullup enabled
  for (unsigned i = 14; i < 21; i++) { //14,15,16,20
    pinMode(i, INPUT_PULLUP);
  }
//  pinMode(testpin, INPUT_PULLUP);
//  pinMode(LEDPin, OUTPUT);  // LED pin
  button_pressed = false;
  ButtonVal = 1;
}


void loop() {
  if (button_pressed)
  {
    a.setProgression(ButtonVal - 1);
    button_pressed = false;
//    digitalWrite(LEDPin, HIGH);   // Switch on LED
    a.play();
//    digitalWrite(LEDPin, LOW);    // Switch off LED
  }
}


// Arrange the N elements of ARRAY in random order.
void shuffle(int *array, size_t n)
{
  if (n > 1)
  {
    size_t i;
    for (i = 0; i < n - 1; i++)
    {
      size_t j = i + rand() / (RAND_MAX / (n - i) + 1);
      int t = array[j];
      array[j] = array[i];
      array[i] = t;
    }
  }
}

void arp::setupArp(short bn, short bo, short os, unsigned short st, unsigned int de, int od, unsigned mo)
{
  //baseNote = (notes) map(bn, 0, 800, 0, 11);
  //baseOctave = (short) map(bo, 0, 800, 0, 7);
  //octaveShift = (short) map(os, 0, 800, 0, 7);
  baseNote = midi4note;
  baseOctave = midi4octave;
  octaveShift = midi3octave;
  
  steps = (unsigned short) map(st, 0, 800, 1, 6);
  indelay = (unsigned int) map(de, 0, 800, 0, 500);
  mode = all_chords[(unsigned int) map(mo, 0, 800, 0, 8)];
  order = (unsigned int) map(od, 0, 800, 0, 4);

  leds[3] = CHSV(map(indelay, 0, 500, 0, 200), 255, 64);
  leds[2] = CHSV(map(mode, 0, 8, 0, 200), 255, 64);
  leds[1] = CHSV(map(order, 0, 4, 0, 200), 255, 64);
  leds[0] = CHSV(map(steps, 1, 6, 0, 200), 255, 64);
}

int arp::setProgression(unsigned int p)
{
  if (p < 8)
  {
    progression = p;
    return 0;
  }
  else
    return -1;
}

int* createChord(notes root, chord_types i, int *notes_array, unsigned short *sh1, unsigned short *sh2)
{
  *sh1 = 0; *sh2 = 0;
  int s1, s2;
  switch (i) {
    case maj:   s1 = 4; s2 = 7; break;
    case minor: s1 = 3; s2 = 7; break;
    case dim:   s1 = 3; s2 = 6; break;
    case aug:   s1 = 4; s2 = 8; break;
  }
  notes_array[0] = root;
  notes_array[1] = (root + s1) % 12;
  if (root + s1 > 11) *sh1 = 1; // octave shift
  notes_array[2] = (root + s2) % 12;
  if (root + s2 > 11) *sh2 = 1; // octave shift
}

short midiByNote (notes note, short octave)
{
  if ((octave < -1) || (octave > 8))
    return -1;

  return (octave + 1) * 12 + (int)note;
}

void arp::play()
{
  int i;
  short n, shift, oct_shift = 0, bn;
  unsigned short sh1, sh2, notes_added = 0;
  notes curNote[3];
  short notestoplay[15] = {0, 0, 0, 0, 0, 0, 0, 0, 0, 0};
  // Play base note
  if ((int)baseNote + (int)mode[progression].Shift > 11)
    baseOctave++;
  i = (baseNote + mode[progression].Shift) % 12;
  bn = midiByNote ((notes)i, baseOctave);
  memset(notestoplay, sizeof(notestoplay), 0);

  // Create chord (notes root, intervals i, int *notes_array)
  createChord((notes)i, mode[progression].chord_type, (int*)curNote, &sh1, &sh2);

  // Create the progression
  if ((order == 0) || (order == 2) || (order == 3))
    for (i = 0; i < steps; i++)
    {
      shift = i % 3;
      oct_shift = i / 3;
      if (shift == 1)
        oct_shift += sh1;
      if (shift == 2)
        oct_shift += sh2;
      notestoplay[notes_added] = midiByNote (curNote[shift], octaveShift + oct_shift);
      notes_added++;
    }
  if ((order == 1) || (order == 2) || (order == 2))
    for (i = steps - 1; i >= 0; i--)
    {
      shift = i % 3;
      oct_shift = i / 3;
      if (shift == 1)
        oct_shift += sh1;
      if (shift == 2)
        oct_shift += sh2;
      notestoplay[notes_added] = midiByNote (curNote[shift], octaveShift + oct_shift);
      notes_added++;
    }

  if (order == 3)
    shuffle(notestoplay, notes_added);
  //Serial.print(bn); Serial.print("\r\n");
  midi.sendNoteOn({bn, CHANNEL_2}, 1);
  for (i = 0; i < notes_added; i++)
  {
    Serial.print(notestoplay[i]); Serial.print(" ");
    midi.sendNoteOn({notestoplay[i], CHANNEL_1}, 127);

#ifdef INT_SYNC
    // Delay value from poti
    delay(indelay);
#endif

#ifdef EXT_SYNC
    // Wait for click from sync in
    while ((digitalRead(syncinpin) == 0));
    delay(65);
#endif

    // Stop note
    midi.sendNoteOff({notestoplay[i], CHANNEL_1}, 0);    // Stop the note
  }

  //Stop base note
  midi.sendNoteOff({bn, CHANNEL_2}, 0);
}

arp::arp(notes bn, short bo, short os, unsigned short st, unsigned int d, unsigned m, unsigned int p) : baseNote(bn), baseOctave(bo), octaveShift(os), steps(st), indelay(d), progression(p)
{
  order = 0;
  mode = all_chords[m];
}

arp::arp()
{
  int i;
  baseNote = D;
  baseOctave = 5;
  octaveShift = -2;
  steps = 6;
  indelay = 200;
  progression = 0;
  mode = ionian;
}

void arp::midibegin()
{
  //  midi.begin(); // Initialize the MIDI interface
  //  midi.setCallbacks(callbacks); // Attach the custom callback
  //Serial.begin(57600);
}

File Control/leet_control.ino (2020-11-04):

//-----10|-------20|-------30|-------40|-------50|-------60|-------70|-------80|
//
// -=*** LEET control module ***=-
//
// The device sends MIDI commands over USB when knobs or keys are adjusted
// Uses Arduino pro micro (atMega32U4), WS2812 led strips & 7 keys
// connected between microcontroller and GND (using weak pull-ups).
// Latest version, details and build instructions is found on www.vonkonow.com
//
// This code is open source under MIT License.
// (attribution is optional, but always appreciated - Johan von Konow ;)
//
// Future improvements:
// * improve how midi-ch and octaves are visualized (if > 4)
//
// History: 2020-11-04
// * added startup LED animation
// * midichannel is stored in (non volatile) eeprom memory
// * improved octave and midi-ch visualzation
// * cleaned up code

#include <MIDIUSB.h>
#include <NeoPixelBrightnessBus.h>
#include <EEPROM.h>

const bool debug = false;                         // <- serial debugging over USB
const bool echoLed = true;                        // <- echo LED without incoming MIDI
const bool startAnimation = true;                 // <- show start animation
const uint8_t ledBrightness = 42;                 // <- LED intensity (0-255)
const uint8_t noteIntensity = 64;                 // <- MIDI note volume (0-127)
const uint8_t anIn = 4;                           // number of analog filters
const uint8_t anNum = 16;                         // amount of filter to hide noise
const uint8_t anPin[anIn] = {A9, A8, A7, A6};     // analog inputs
const uint8_t maxLeds = 4;
const uint8_t maxNotes = 4;
const uint8_t maxKeys = 7;
const uint8_t ledPin = 2;
const uint8_t pot1 = A9;
const uint8_t pot2 = A8;
const uint8_t pot3 = A7;
const uint8_t pot4 = A6;
const uint8_t keyModePin = 19;
const uint8_t keyOctUpPin = 18;
const uint8_t keyOctDownPin = 10;
const uint8_t keyMap[maxKeys] = {20, 16, 15, 14, 19, 18, 10};
const uint8_t ledMap[maxNotes] = {3, 2, 1, 0};

// Runnig average analog filter:
uint8_t anPos;                                    // the index of the current reading
int anHistory[anIn][anNum];                       // the lst readings from the analog input
int anOld[anIn];                                  // analog old reading (detect change)
int anTotal[anIn];                                // the running total
int anAvg[anIn];                                  // analog average

uint16_t pressedKeys = 0x00;
uint16_t previousKeys = 0x00;
uint8_t octave = 0;                               // offset to midi control commands
uint8_t midiCh;                                   // loaded from EEPROM at startup
bool fadeLeds = false;


NeoPixelBrightnessBus<NeoGrbFeature, Neo800KbpsMethod> strip(maxLeds, ledPin);

//-----10|-------20|-------30|-------40|-------50|-------60|-------70|-------80|

void setup() {
  for (int i = 0; i < maxKeys; i++)
    pinMode(keyMap[i], INPUT_PULLUP);
  if (debug == true) {
    Serial.begin(115200);
    Serial.println("Serial debug enabled: ");
  }

  midiCh = EEPROM.read(0);
  if (midiCh > 15) {                              // if default eeprom value is outside ch range
    midiCh = 0;
    EEPROM.update(0, midiCh);
  }

  strip.Begin();
  strip.SetBrightness(ledBrightness);
  if (startAnimation == true)
    showLedAnimation();
}

void loop() {
  checkKeys();                                    // user input (including knobs)
  sendControl();                                  // send control messages if user input
  updateLEDs();                                   // Show knob value or fade octave and midi ch LEDs
}

void checkKeys() {
  // get analog input (filtered)
  anUpdate();
  
  // check notes
  for (int i = 0; i < maxNotes; i++) {
    if (digitalRead(keyMap[i]) == LOW) {
      bitWrite(pressedKeys, i, 1);
    } else
      bitWrite(pressedKeys, i, 0);
  }
  
  // check midi channel
  if (digitalRead(keyModePin) == 0) {
    showMidi();
    while (digitalRead(keyModePin) == 0) {
      // midi up?
      if (digitalRead(keyOctUpPin) == 0) {
        if (midiCh < 15)
          midiCh++;
        showMidi();
        EEPROM.update(0, midiCh);
        while (digitalRead(keyOctUpPin) == 0)
          delay(20);
      }
      // midi down?
      if (digitalRead(keyOctDownPin) == 0) {
        if (midiCh > 0)
          midiCh--;
        showMidi();
        EEPROM.update(0, midiCh);
        while (digitalRead(keyOctDownPin) == 0)
          delay(20);
      }
      delay(20);
    }
  }
  
  // Octave Up
  if (digitalRead(keyOctUpPin) == 0) {
    if (octave < 9)
      octave++;
    showOctave();
    while (digitalRead(keyOctUpPin) == 0)
      delay(20);
  }
  
  // Octave Down
  if (digitalRead(keyOctDownPin) == 0) {
    if (octave > 0)
      octave--;
    showOctave();
    while (digitalRead(keyOctDownPin) == 0)
      delay(20);
  }
}

void anUpdate() {
  for (uint8_t i = 0; i < anIn; i++) {
    anTotal[i] = anTotal[i] - anHistory[i][anPos];  // subtract the last reading:
    anHistory[i][anPos] = analogRead(anPin[i]) / 8; // read from the sensor: 0-1023 => 0-127
    anTotal[i] = anTotal[i] + anHistory[i][anPos];  // add the reading to the anTotal:
  }
  anPos++;                                          // advance to the next position in the array:
  if (anPos >= anNum)                               // if we're at the end of the array...
    anPos = 0;                                      // ...wrap around to the beginning:
  for (uint8_t i = 0; i < anIn; i++) {
    anAvg[i] = anTotal[i] / anNum;                  // calculate the average:
  }
}

void updateLEDs() {
  if (fadeLeds == true) {                           // fade status leds? (change chord length, octave or midi)
    fadeLeds = false;
    for (uint8_t i = 0; i < maxLeds; i++) {
      RgbColor tmpColor = strip.GetPixelColor(i);
      tmpColor.Darken(1);
      if (tmpColor != RgbColor(0, 0, 0))
        fadeLeds = true;
      strip.SetPixelColor(i, tmpColor);
    }
    delay(10);
    strip.Show();
  } else {
    strip.SetPixelColor(3, wheelH(map(anAvg[0], 0, 127, 0, 654)));
    strip.SetPixelColor(2, wheelH(map(anAvg[1], 0, 127, 0, 654)));
    strip.SetPixelColor(1, wheelH(map(anAvg[2], 0, 127, 0, 654)));
    strip.SetPixelColor(0, wheelH(map(anAvg[3], 0, 127, 0, 654)));
  }
  strip.Show();
}

void showMidi() {
  for (uint8_t i = 0; i < maxLeds; i++) {
    if (i <= midiCh)
      strip.SetPixelColor(ledMap[i], wheelH(map(i, 0, 16, 0, 767)));
    else
      strip.SetPixelColor(ledMap[i], RgbColor(0, 0, 0));
    strip.Show();
  }
  fadeLeds = true;
}

void showOctave() {
  for (uint8_t i = 0; i < maxLeds; i++) {
    if (i <= octave)
      strip.SetPixelColor(ledMap[i], wheelH(map(i * 12, 0, 128, 0, 767)));
    else
      strip.SetPixelColor(ledMap[i], RgbColor(0, 0, 0));
    strip.Show();
  }
  fadeLeds = true;
}
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

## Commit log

2020-10-28 .STL Polygon mesh model for 3D printer
    initial commit
2020-10-28 Source code for Arduino pro micro (atMega32U4)
    Initial commit
2020-11-02 Keyboard in two parts (not tested)
    I got a question if the keyboard could be split in two for a 3d printer with 10x10cm build area.
    Here is two parts with a 2D dovetail. One switch is also joining the two halves.
    Hope it works...
2020-11-02 3D models (stl for 3d printer, stp for editing)
    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
    [knob_pot.stl, knob_pot.stp, knob_trim.stl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]
2020-11-04 Version of keyboard with support under keys.
    This is a test to improve 3D printing performance. The middle part under the keys is now connected to the first layer, reducing risk of faulty prints (maybe at the cost of less space for soldering)
2020-11-04 Source code for Arduino pro micro (atMega32U4)
    // History: 2020-11-02
    // * updated to MIT license
    // * fixed wheelH
    [leet_keyboard.ino]
2020-11-06 Delete keyboard_stl.zip
    replaced by new version, better suited for 3d printing (removed loose parts in first layer)
2020-11-06 Delete keyboard_stp.zip
    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
2020-11-06 .STL Polygon mesh model for 3D printer
    improved version, better suited for 3d printing (removed loose parts in first layer)
2020-11-06 .STP NURBS model for editing in 3DCAD
    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
2020-11-07 .STL Polygon mesh model for 3D printer
    Now with correct file inside...
    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
2020-11-07 Source code for Arduino pro micro (atMega32U4)
    Adjusted analog inputs to match 3DPCB {A9, A8, A6, A4};
2020-11-07 Source code for Arduino pro micro (atMega32U4)
    Reversed previous change (mixed digital and analog pin names)
    {A9, A8, A7, A6} is using digital 9,8,6,4...
    [leet_control.ino]
2020-11-07 .STL Polygon mesh model for 3D printer
    identical model as used in LEET Control
    inital commit
2020-11-07 Source code for Arduino pro micro (atMega32U4)
    Proof of concept code
    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
2020-11-14 Delete keyboard_modified.stl
    I have now implemented this change in the models for the LEET units.
2020-11-14 .STP NURBS model for editing in 3DCAD
    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
    [leet_test.stp]
2020-11-17 Project description
    All devices in first video are now posted :)
2020-11-19 Source code for Arduino pro micro (atMega32U4)
    Previous commit was LEET control, by mistake ;(
    [leet_pad.ino]
2020-12-25 SamplerBox Files (Scripts & OLED images)
    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
2021-01-11 bugfix in samplerbox.py
    Removed backslash that caused problem loading some sample sets.
    Thank you to rynfox13 for finding this error!
2021-01-20 .STL Polygon mesh model for 3D printer
    Now including the trimpot knob (rotated compared to the one in the accessory folder)
